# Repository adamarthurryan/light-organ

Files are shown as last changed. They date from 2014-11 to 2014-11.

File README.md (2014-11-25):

light-organ
===========

The light organ is an audio visualizer or special effects controller. The device is an electronic a 3-channel dimmer for incandescent lights. Each channel interprets the amplitude of one frequency band from the input audio.

This device was used in the interactive sound ard installation "infinite space kaleidoscope" by Adam Brown. See http://madanworb.com/blog/2011/02/01/infinite-space-kaleidoscope/

# Hardware

The dimmer is implemented with TRIAC switches, signaled through optoisolators. The dimmer controller and sound analyzer is implemented with an Atmel ATXMega128A1 8-bit microcontroller. 

The dimmer circuitry also provides a rectified AC-sync signal at 2.5V. The controller analyzes this signal to determine when the TRIAC should be switched on at each point in the AC waveform. (Recall that TRIACs can only be switched off at zero-crossing, so dimmer PWM has to be syncronized to the AC carrier wave.)

Circuits were designed in the free edition of Eagle. Schematics and burnable board layouts are included in the "circuits/light organ base" and "circuits/light organ controller" folders.

# Software

The controller software is implemented for the Atmel ATXMega128A1 - an 8-bit, 32MHz microcontroller. The responsibilities of the controller software are to:
- analyze an input waveform to find amplitudes in the three target frequency bands
- analyze the AC-sync signal to determine the mains frequency and phase
- signal the amplitude for each channel by switching the TRIACs

The software is developed and compiled with Atmel AVR Studio and depends on the XMega appnote library.

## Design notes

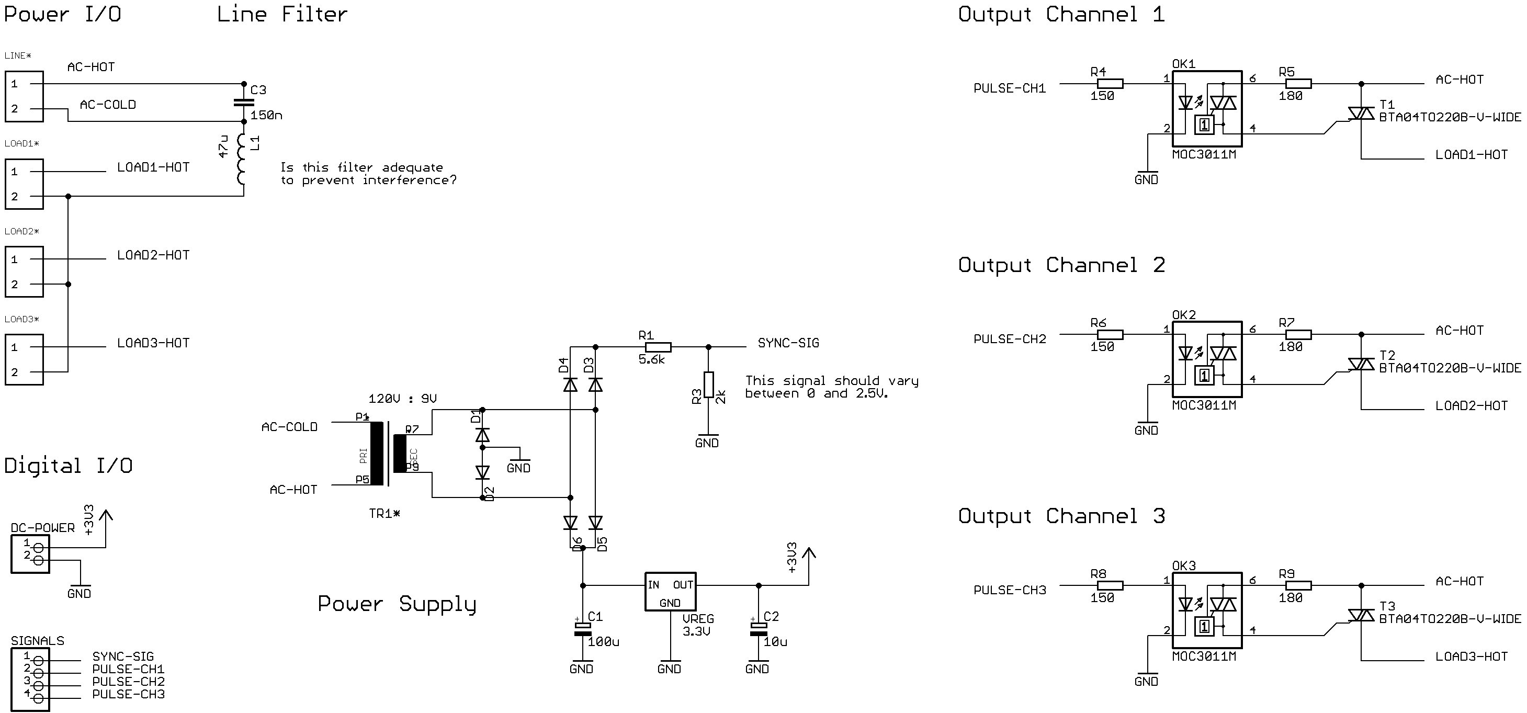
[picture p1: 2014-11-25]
circuits/light organ base/schematic.png

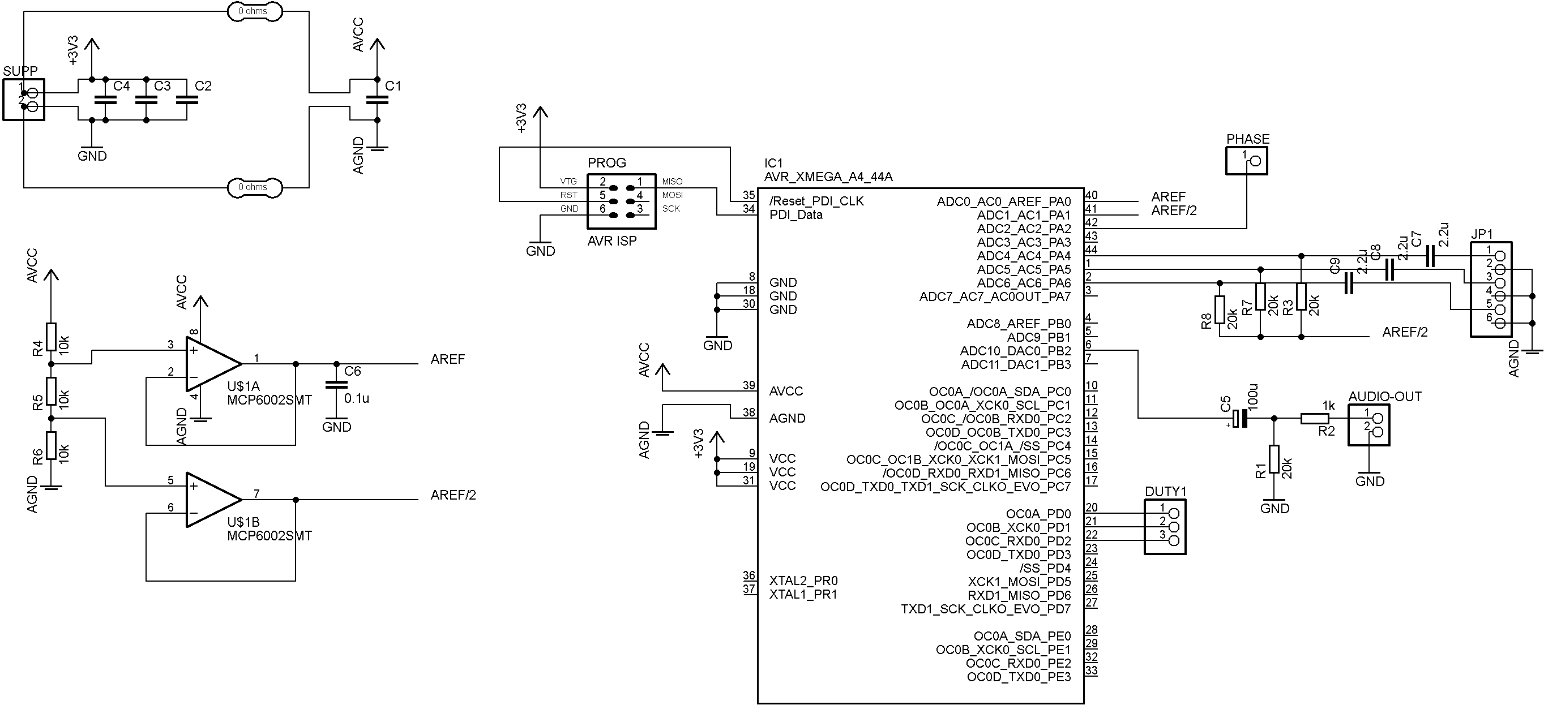
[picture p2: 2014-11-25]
circuits/light organ controller XMEGA A4/schematic.png

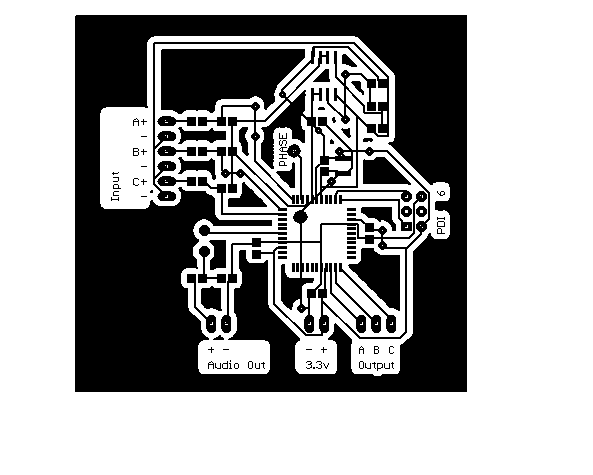
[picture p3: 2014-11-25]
circuits/light organ controller XMEGA A4/board.png

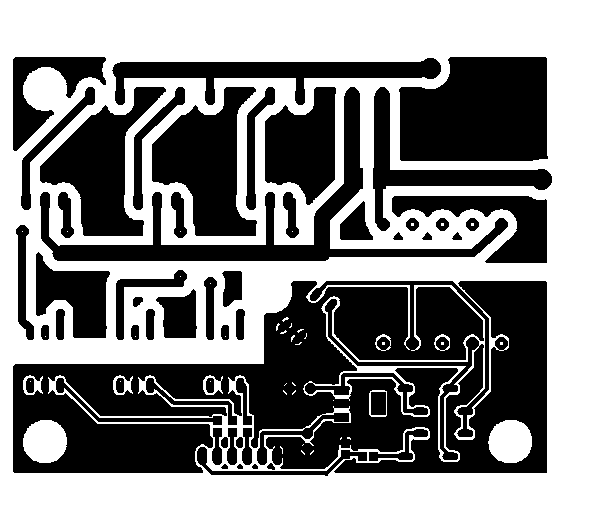
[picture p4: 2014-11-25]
circuits/light organ base/board.png

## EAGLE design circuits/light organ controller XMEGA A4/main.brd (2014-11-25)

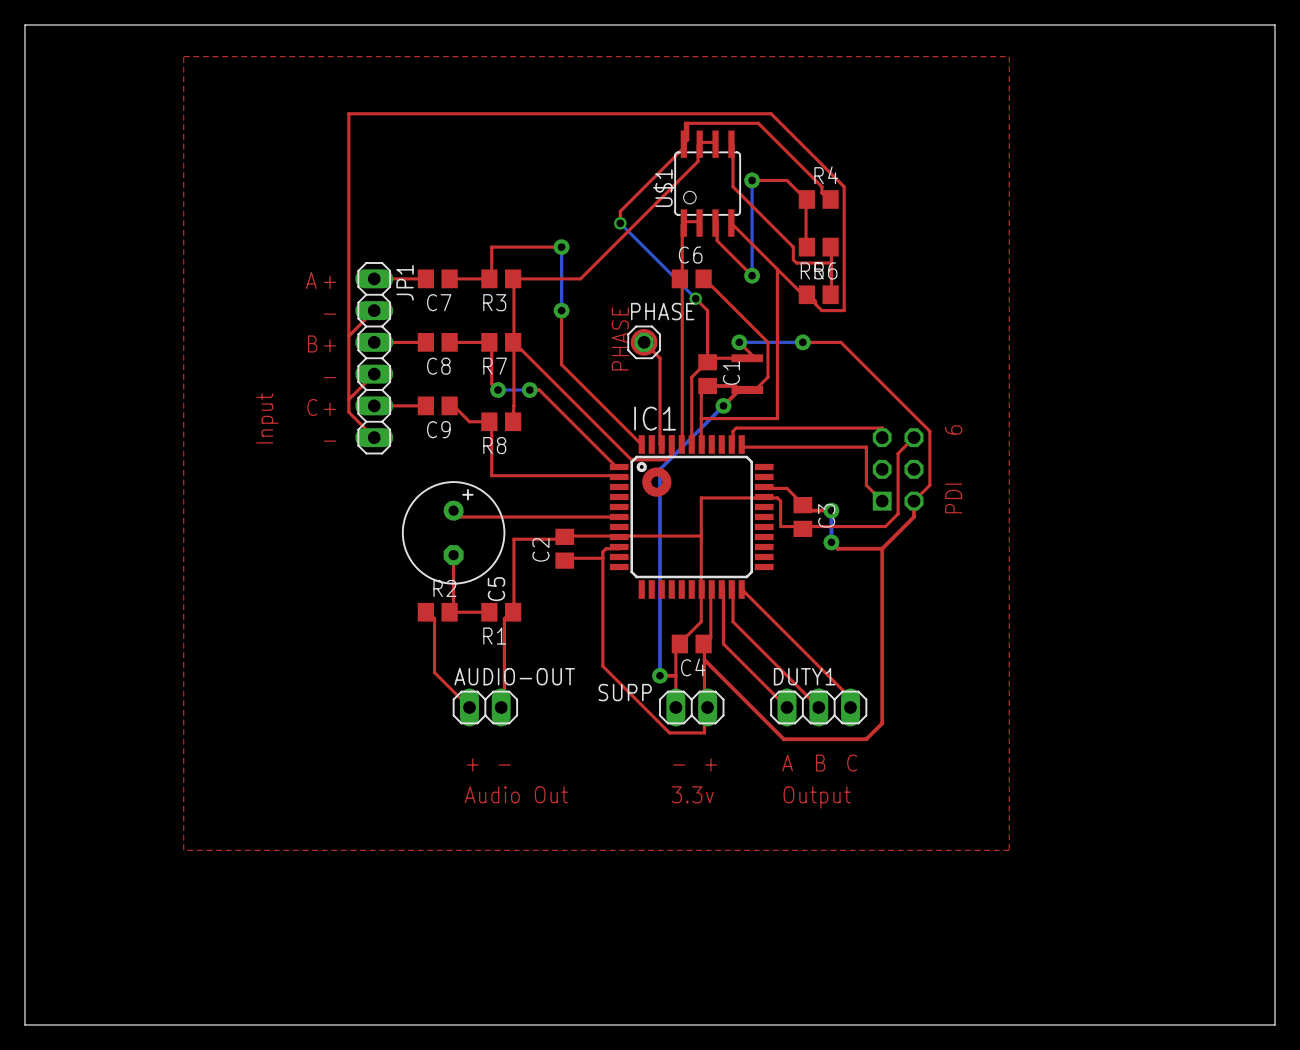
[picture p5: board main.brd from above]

Board: 2 copper layers, 100.0 x 80.0 mm, 27 parts (1 on the bottom side), 23 nets.

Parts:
AUDIO-OUT: 1X02
C1, C2, C3, C4: C0805
C5: 100u; E3,5-8
C6: 0.1u; C0805
C7, C8, C9: 2.2u; C0805
DUTY1: 1X03
IC1: AVR_XMEGA_A4_44A; TQFP44
JP1: 1X06
PHASE: 1X01
PROG: AVR-ISP-6
R1, R3, R7, R8: 20k; R0805
R2: 1k; R0805
R4, R5, R6: 10k; R0805
SUPP: 1X02
U$1: MCP6002SMT; SOIC8
U$2, U$4: RESISTOR-0; JOINED-PADS

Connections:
+3V3: C2.1, C3.1, C4.1, IC1.9, IC1.19, IC1.31, PROG.2, SUPP.1, U$2.P$1
AGND: C1.2, IC1.38, JP1.2, JP1.4, JP1.6, R6.1, U$1.4, U$4.P$2
AREF: C6.1, IC1.40, U$1.1, U$1.2
AREF/2: IC1.41, R3.1, R7.1, R8.1, U$1.6, U$1.7
AVCC: C1.1, IC1.39, R4.2, U$1.8, U$2.P$2
GND: AUDIO-OUT.2, C2.2, C3.2, C4.2, C6.2, IC1.8, IC1.18, IC1.30, PROG.6, R1.1, SUPP.2, U$4.P$1
IN1: C7.2, JP1.1
unnamed: IC1.35, PROG.5
unnamed: C5.+, IC1.6
unnamed: IC1.34, PROG.1
unnamed: C5.-, R1.2, R2.2
unnamed: AUDIO-OUT.1, R2.1
unnamed: C7.1, IC1.44, R3.2
unnamed: IC1.42, PHASE.1
unnamed: C8.2, JP1.3
unnamed: R4.1, R5.2, U$1.3
unnamed: R5.1, R6.2, U$1.5
unnamed: C9.2, JP1.5
unnamed: C8.1, IC1.1, R7.2
unnamed: C9.1, IC1.2, R8.2
unnamed: DUTY1.1, IC1.20
unnamed: DUTY1.2, IC1.21
unnamed: DUTY1.3, IC1.22

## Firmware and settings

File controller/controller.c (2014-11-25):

/*
	Light Organ

	Improvements to be made:
		allow multiple input sources (multiple ADC channels)
		allow switches to configure input source, or filter bands
		incorporate beat detection
		increase the duty cycle setting resolution (to 11 bits, say)

	Problems:
		the low pass filter always seems to register a signal
		maybe this is 60 Hz hum?
*/

/* !!! try flattening dynamics of output:
	- clip output to 0 / 1 
 try other frequency bands*/

#include <avr/io.h>

//standard library
#include <stdbool.h>
#include <stdint.h>
#include <stdlib.h>
#include <stdio.h>
#include <math.h>
#include <util/delay.h>


//peripheral drivers
#include "clksys_driver.h"
#include "event_system_driver.h"
#include "tc_driver.h"
#include "pmic_driver.h"
#include "ac_driver.h"
#include "adc_driver.h"
#include "dac_driver.h"

//device drivers
#include "display.h"


//helper
	#define max(a,b) ((a>b)?a:b)
	#define min(a,b) ((a<b)?a:b)

//filter options
	#define FILTERS_ENABLE
//	#define ANTIALIAS_ENABLE
	#define ANTIALIAS_RATE 2
	//the following is log(ANTIALIAS_RATE)
	#define ANTIALIAS_SHIFT 1

//input options
	#define INPUT_CLONE_SAMPLE0

//debug-mode options
//	#define DISPLAY_ENABLE
//	#define	FLASHER_ENABLE

//	#define PRINT_DEBUG
//	#define PRINT_DUTY_CYCLES

	#define DEBUG_FILTER_TEST
//	#define DEBUG_CLONE_DUTY0

//peripheral configuration
	#define UI_timer TCD0
	#define UI_vect TCD0_OVF_vect

	#define ms_UI_interval 1

	#define PHASE_timer TCE0
	#define PHASE_port PORTD

	#define EFFECTIVE_rate 11000
	#ifdef ANTIALIAS_ENABLE
		#define SAMPLE_rate (EFFECTIVE_rate * ANTIALIAS_RATE)
	#endif
	#ifndef ANTIALIAS_ENABLE
		#define SAMPLE_rate EFFECTIVE_rate
	#endif

	#define SAMPLE_timer TCD1
	#define SAMPLE_evsrc EVSYS_CHMUX_TCD1_OVF_gc

	#define CAPTURE_timer TCC1
	#define CAPTURE_vect TCC1_OVF_vect
	
	//the number of samples to collect in a bin for the beat detection algorithm
	//binsize must equal 2^binbits
	//note that the sound intensity will be sampled at rate/binsize, choose a binsize to make this around 40 Hz
	#define CAPTURE_binsize 256 //### 1024 //### 32 //###256
	#define CAPTURE_binbits 8 //### 10 //### 5 //###8
	
	#define HISTORY_size 43 //### 43

	#define AC_pin AC_MUXPOS_PIN2_gc

	//the gain for the ADC
	//this is configured for use with line level audio
	#define ADC_gain ADC_CH_GAIN_2X_gc

	//the pin for the AREF / 2 mid level reference voltage (for positive and negative ADC MUX)
	#define ADC_AREF_DIV_2_MUXPOS_pin ADC_CH_MUXPOS_PIN1_gc
	#define ADC_AREF_DIV_2_MUXNEG_pin ADC_CH_MUXNEG_PIN1_gc

//event related variables
	volatile uint32_t msClock=0;

	//these phase variables are expressed in terms of ticks of the phase clock
	uint16_t phasePeriod=0;
	volatile uint16_t phasePeriodLast=0;
	uint16_t phasePeriodMin=3200;

	volatile bool fPhaseBegin=false;
	volatile bool fPhaseEnd=false;
	volatile bool fSampleCaptured=false;
	volatile bool fCaptureBinFilled=false;

//	volatile uint16_t sampleLast=0;
//	volatile uint16_t sampleMax=0;
//	volatile uint16_t sampleMin=4096;

//	volatile uint32_t sampleSum=0;
//	volatile uint16_t sampleSumCount=0;

	volatile uint8_t dutyA, dutyB, dutyC;

//debugging variables
	volatile uint16_t debug1, debug2, debug3, debug4;

//a string for building output
	char string [17];

//the error offset of the adc
	int16_t ADC_offset=0;




//function prototypes
	void initializeMCU();
	void initializeUITimer();
	void initializePhaseTimer();
	void initializePhaseComparator();
	void initializeSampleTimer();
	void initializeCaptureTimer();
	void initializeADC();

	void initializeDAC();

	void enableInterrupts();

	void setDutyCycles(uint8_t, uint8_t, uint8_t);
	void findPhasePeriod();

	void error(char *);

	void printDutyCycles();
	void debugFilterTest();

int main(void) {

	//initialize the MCU clock
	initializeMCU();

	#ifdef DEBUG_FILTER_TEST
		debugFilterTest();
	#endif

	//initialize the display and display the title if the display is enabled
	#ifdef DISPLAY_ENABLE
		//initialize the display (the SPI port)
		display_init(16,2);	

		//display the boot screen
		display_returnHome();
		display_printString("Light Organ");
		
	#endif
	
	//initialize peripherals
	initializeUITimer();
	initializePhaseTimer();
	initializePhaseComparator();

	#ifndef FLASHER_ENABLE
		initializeSampleTimer();
		initializeCaptureTimer();
		initializeADC();
		initializeDAC();
	#endif

	enableInterrupts();
	
//	while (true) {
		//find the nominal phase period
		findPhasePeriod();	

		//### hack - because the phase period detection is not working
		//phasePeriod=1800;


		//display the period if the display is enabled
		#ifdef DISPLAY_ENABLE
			display_moveCursor(0x40);
			sprintf(string, "period: %i", phasePeriod);
			display_printString(string);
//			_delay_ms(1000);
			_delay_ms(300);
		#endif
//	}

	#ifdef DISPLAY_ENABLE
		volatile uint32_t msDisplayUpdate=0;
		#define DISPLAY_PERIOD 100
	#endif


	//some variables for generating fun duty cycle changes
	#ifdef FLASHER_ENABLE
		int value=1;
		int dir=1;
		int step=2;
		int stepdir=1;
		int stepstep=1;
	#endif

	volatile uint32_t msValueUpdate=0;
//	uint16_t energy=0;
	volatile uint32_t msStrobe=0;

	//enter the main event loop
	while (true) {
		//keep track of the minimum phase period
		if (fPhaseEnd) {

			//PHASE_port.OUTCLR = PIN0_bm;
			fPhaseEnd=false;
			phasePeriodMin=(phasePeriodLast<phasePeriodMin) ? phasePeriodLast : phasePeriodMin;
			//debug3=phasePeriodLast;
		}

//		if(msClock>=msStrobe) {
//			PHASE_port.OUTTGL=PIN1_bm;
//			msStrobe=msClock+2;
//		}


		#ifdef FLASHER_ENABLE
			//update the value to create a flashing light effect
			if (msClock>=msValueUpdate) {
				setDutyCycles(value, 255-value, 255-value);

				phasePeriodMin=30000;

				if (step<=1 || step>=128)
					stepdir=-stepdir;

				if (value<=0 || value>=255) {
					dir=-dir;
					step+=stepdir*stepstep;
				}
				value+=dir*step;

				if (value<0) value=0;
				if (value>255) value=255;
			
				msValueUpdate+=30;
			}
		#endif



		//update the display
		#ifdef DISPLAY_ENABLE
			if (msClock>=msDisplayUpdate) {
				display_moveCursor(0x0E);
				display_printString("  ");

				if (fSampleCaptured) {
					display_moveCursor(0x0E);
					display_printChar('S');
					fSampleCaptured=false;
				}

				if (fCaptureBinFilled) {
					display_moveCursor(0x0F);
					display_printChar('F');
					fCaptureBinFilled=false;
				}

				#ifdef PRINT_DEBUG
					sprintf(string, "%5i ", debug1);
					display_moveCursor(0x00);
					display_printString(string);

					sprintf(string, " %5i", debug2);
					display_moveCursor(0x06);
					display_printString(string);

					sprintf(string, "%5i ", debug3);
					display_moveCursor(0x40);
					display_printString(string);

					sprintf(string, " %5i", debug4);
					display_moveCursor(0x46);
					display_printString(string);
				#endif

				#ifdef PRINT_DUTY_CYCLES
					printDutyCycles();
				#endif

				msDisplayUpdate+=DISPLAY_PERIOD;
			}
		#endif

	}
}


//print the duty cycle to the display
void printDutyCycles() {
	sprintf(string, "a:%2X, b:%2X, c:%2X", dutyA, dutyB, dutyC);
	display_moveCursor(0x40);
	display_printString(string);
}

//set the duty cycle for each output channel
//duty cycle is expressed as a byte value
//0 is fully off, 255 is fully on
void setDutyCycles(uint8_t _dutyA, uint8_t _dutyB, uint8_t _dutyC) {
	//save the duty settings as global variables (for debugging)
	dutyA=_dutyA; dutyB=_dutyB; dutyC=_dutyC;

	//calculate the number of ticks given the duty cycle
	uint32_t prodA = (uint32_t) _dutyA * phasePeriod;
	uint16_t ticksA= phasePeriod - (prodA/255);

	//set the timer comparator value
	//the comparator output pins for the phase timer will be the duty cycle output
	TC_SetCompareA(&PHASE_timer, ticksA);

	uint32_t prodB = (uint32_t)_dutyB * phasePeriod;
	uint16_t ticksB=phasePeriod - (prodB/255);
	//note: comparator B didn't work, for some reason, so we use comparator D for output channel B instead
	TC_SetCompareD(&PHASE_timer, ticksB);

	uint32_t prodC = (uint32_t)_dutyC * phasePeriod;
	uint16_t ticksC=phasePeriod - (prodC/255);
	TC_SetCompareC(&PHASE_timer, ticksC);
	
//	debug1=(uint16_t) (prodA/255);
//	debug2=ticksA;
}

//find the noninal AC phase
void findPhasePeriod() {
	uint32_t sum=0;

	uint32_t msTimeout=msClock+10000;

	//average the phase period over one second
	for (int i=0;i<60;i++) {
		while (!fPhaseEnd) {
			if (msClock>=msTimeout)
				error("finding period");
		}
		fPhaseEnd=false;

		sum+=phasePeriodLast;
	}

	phasePeriod=sum/60;
}




//show an error and hang
void error(char * msg) {
	display_clear();
	_delay_ms(3);

	display_moveCursor(0x00);
	display_printString("ERROR");
	display_moveCursor(0x40);
	display_printString(msg);

	while (true) 
		nop();
}

//the UI timer interrupt
ISR(UI_vect)
{
	msClock+=ms_UI_interval;
}




//the analog comparator rising edge interrupt
//note this is mislabeled as "COMP0_vect" in the ATXMEGA datasheet!
ISR(ACA_AC0_vect)
{
	//turn on the counter
	TC0_ConfigClockSource(&PHASE_timer, TC_CLKSEL_DIV64_gc);   

	//flag that a zero-cross rising edge event has occured
	fPhaseBegin=true;

}

//the analog comparator falling edge interrupt
//note this is mislabeled as "COMP1_vect" in the ATXMEGA datasheet!
ISR(ACA_AC1_vect)
{
	//turn off phase timer
	TC0_ConfigClockSource(&PHASE_timer, TC_CLKSEL_OFF_gc);   

	//reset the output pins
	PHASE_port.OUTCLR = PIN0_bm | PIN1_bm | PIN2_bm;

	//force update of compare values
	//this would normally happen when the counter overflows
	TC_ForceUpdate(&PHASE_timer);

	//read the counter
	phasePeriodLast=PHASE_timer.CNT;

	//set the counter to 0 and clear the comparators
	TC_Restart(&PHASE_timer);

	//flag that a zero-cross falling edge event has occured
	fPhaseEnd=true;

}

//the interrupts for the comparators - when a comparator is triggered, turn on the cooresponding pin
//these could possibly be optimized by making them ISR_NAKED and doing the setup by hand
ISR(TCE0_CCA_vect) {
	PHASE_port.OUTSET = PIN0_bm;
}
ISR(TCE0_CCD_vect) {
	PHASE_port.OUTSET = PIN1_bm;
}
ISR(TCE0_CCC_vect) {
	PHASE_port.OUTSET = PIN2_bm;
}


//record the maximum sample level for debugging
uint16_t maxLevel=0;

//the number of input channels
#define INPUT_CHANNELS 3

//!!! These should be initialized to 0
//keeps a running tally of the energy for each sample
uint32_t energy_sum[INPUT_CHANNELS];


#ifdef FILTERS_ENABLE
	//the following variables are used for the three bandpass filters
	int32_t lowband_x0=0, lowband_x1=0, lowband_x2=0;
	int32_t lowband_y0=0, lowband_y1=0, lowband_y2=0;

	int32_t midband_x0=0, midband_x1=0, midband_x2=0;
	int32_t midband_y0=0, midband_y1=0, midband_y2=0;

	int32_t highband_x0=0, highband_x1=0, highband_x2=0;
	int32_t highband_y0=0, highband_y1=0, highband_y2=0;
 
 	#define FILTER_CONSTANT_SHIFT 12

//These were created using Interactive Digital Filter Design, http://www-users.cs.york.ac.uk/~fisher/mkfilter
// (and made fixed point with filters.php)
// they are shifted to have 12 fractional bits (ie. Q20.12 format)

// lowband_: 160-320 HZ
#define lowband_INVGAIN 386
#define lowband_B0 3549
// midband_: 2500-4000 HZ
#define midband_INVGAIN 1603
#define midband_B0 -891
#define midband_B1 -843
// highband_: 4000-5500 HZ
#define highband_INVGAIN 1572
#define highband_B0 -1139
#define highband_B1 -4864

	//compute a fast lowpass filter using the given parameters and sample history
	//the filter constants are assumed to have FILTER_CONSTANT_SHIFT fractional bits
	#define fastlowpass(sample, x0, x1, y0, y1, invgain, b0) \
		x0=x1; y0=y1;\
		x1=(sample*invgain);\
		y1=((x0+x1) + (b0 *y0)) >> FILTER_CONSTANT_SHIFT;\
		sample=y1;

	//compute a fast bandpass filter using the given parameters and sample history
	//the filter constants are assumed to have FILTER_CONSTANT_SHIFT fractional bits
	#define fastbandpass(sample, x0, x1, x2, y0, y1, y2, invgain, b0, b1) \
		x0=x1; x1=x2; y0=y1; y1=y2;\
		x2=(sample*invgain) ;\
		y2=((x2-x0) + (b0*y0) + (b1*y1)) >> FILTER_CONSTANT_SHIFT;\
		sample=y2;


	#ifdef DEBUG_FILTER_TEST
		#define TEST_SAMPLES 16
		#define TO_FIXED(x) ((int32_t)(x*(1<<12)))
		#define TO_FIXED_SMP(x) ((int32_t)(x*2048))
		void debugFilterTest() {
			int16_t results[TEST_SAMPLES];
		
			int32_t x0=0, x1=0, x2=0, y0=0, y1=0, y2=0;
			int32_t b0 = lowband_B0;
			int32_t b1 = 0;
			int32_t invgain = lowband_INVGAIN;
		

			int32_t x0_hist [TEST_SAMPLES];			
			int32_t x1_hist [TEST_SAMPLES];			
			int32_t x2_hist [TEST_SAMPLES];			
			int32_t y0_hist [TEST_SAMPLES];			
			int32_t y1_hist [TEST_SAMPLES];			
			int32_t y2_hist [TEST_SAMPLES];			

			int32_t sample=2048;
			fastlowpass(sample, x0, x1, y0, y1, invgain, b0);
			//for (int i=0; i<1000; i++) {
			//	sample=0;
			//	fastlowpass(sample, x0, x1, y0, y1, invgain, b0);
			//}
			

			for (int i=0; i<TEST_SAMPLES; i++) {
				sample=0;
				fastlowpass(sample, x0, x1, y0, y1, invgain, b0);

				x0_hist[i]=x0;
				x1_hist[i]=x1;
				x2_hist[i]=x2;
				y0_hist[i]=y0;
				y1_hist[i]=y1;
				y2_hist[i]=y2;
				results[i]=y2;
			}

			__builtin_avr_delay_cycles(4);
		}
	#endif


#endif

#ifdef ANTIALIAS_ENABLE
	int32_t antialias_sample[INPUT_CHANNELS];
	int8_t antialias_count=0;
#endif

//the sample capture interrupt from the ADC
//the ADC conversion is triggered by the sample timer and this ISR is called when the conversion is complete
ISR(ADCA_CH0_vect) {
	

	//int16_t sample[INPUT_CHANNELS];
	int32_t sample[INPUT_CHANNELS];

	//read the samples (signed)
	sample[0]=ADC_ResultCh_GetWord_Signed(&ADCA.CH0, ADC_offset);

	#ifndef INPUT_CLONE_SAMPLE0
		sample[1]=ADC_ResultCh_GetWord_Signed(&ADCA.CH1, ADC_offset);
		sample[2]=ADC_ResultCh_GetWord_Signed(&ADCA.CH2, ADC_offset);
	#endif




//FUDGE FACTOR!!!
	sample[0]-=84;


#ifdef ANTIALIAS_ENABLE
	//sample into the antialiasing filter
	antialias_sample[0]+=sample[0];

	//only process channels 1 and 2 if necessary
	#ifndef INPUT_CLONE_SAMPLE0
		antialias_sample[1]+=sample[1];
		antialias_sample[2]+=sample[2];
	#endif

	antialias_count++;

	//if the antialiasing filter is "full" output the signal
	if (antialias_count>=ANTIALIAS_RATE) {
		sample[0] = antialias_sample[0] >> ANTIALIAS_SHIFT;
		antialias_sample[0]=0;
		//only process channels 1 and 2 if necessary
		#ifndef INPUT_CLONE_SAMPLE0
			sample[1] = antialias_sample[1] >> ANTIALIAS_SHIFT;
			sample[2] = antialias_sample[2] >> ANTIALIAS_SHIFT;
			antialias_sample[1]=0;
			antialias_sample[2]=0;
		#endif
				
		
#endif

#ifndef ANTIALIAS_ENABLE
	if (true) {
#endif

		#ifdef INPUT_CLONE_SAMPLE0
			sample[1]=sample[0];
			sample[2]=sample[0];
		#endif

		#ifdef FILTERS_ENABLE
			debug1=sample[0];
			fastlowpass(sample[0], lowband_x0, lowband_x1, lowband_y0, lowband_y1, lowband_INVGAIN, lowband_B0);
		//	sample[0]=0;

		//more FUDGE!!!
			sample[0]-=35;

			debug2=sample[1];
			fastbandpass(sample[1], midband_x0, midband_x1, midband_x2, midband_y0, midband_y1, midband_y2, midband_INVGAIN, midband_B0, midband_B1);

			debug3=sample[2];
			fastbandpass(sample[2], highband_x0, highband_x1, highband_x2, highband_y0, highband_y1, highband_y2, highband_INVGAIN, highband_B0, highband_B1);

		#endif

		//###
		//	sample[0]=sample[0]>>6;
		//	sample[0]=sample[0]<<6;

		//this is only for sample 0?
	//	if (sample[0]>=0) 
	//		maxLevel=max(sample[0],maxLevel);
	//	else
	//		maxLevel=max(-sample[0], maxLevel);


		//take the energy of the samples and add them to the running total
		//we don't shift down by the full 16 (11?) bits, just to leave a little numerical resolution
		for (int i=0;i<INPUT_CHANNELS;i++)
			energy_sum[i]+=((int32_t)sample[i]*sample[i])>>2;

	
				// what about this instead of the square?
				//energy_sum_0+=(sample_0>=0)?sample_0:-sample_0;

		//put a sample to the DAC for debugging
		int16_t sampleOut=sample[0];
		DAC_Channel_Write(&DACB, (uint16_t) (sampleOut + 2048), CH0);//+ADC_offset/2, CH0);


		//increase the sample capture counter by sending event 4
		EVSYS_ManualTrigger(0, 0x10);


		//flag that the sample event occured
		fSampleCaptured=true;
	}
}



uint8_t historyIndex=0;
//should these arrays be initialized to 0?
uint16_t energy_history[INPUT_CHANNELS][HISTORY_size];

//uint32_t lowband_energy_historySum=0;
//uint32_t midband_energy_historySum=0;
//uint32_t highband_energy_historySum=0;

//this interrupt is called after every BINSIZE samples are filtered and summed into their three channels
//here we decide how to respond to the audio signal
ISR(CAPTURE_vect) {

	//###
	debug1=maxLevel;
	maxLevel=0;

	///
	// ** This algorithm is taken from http://www.gamedev.net/reference/articles/article1952.asp **
	///

	// * 1. Take the average input energy from the last bin of samples *
	uint16_t energy_inst[INPUT_CHANNELS];
	
	for (int i=0;i<INPUT_CHANNELS;i++) {
		//grab the sums lickety-quick so they don't change while we are processing
		//and divide them by BINSIZE to find their average
		energy_inst[i]=energy_sum[i] >> CAPTURE_binbits;

		//reset the sums
		energy_sum[i]=0;
	}

	
	// * 2.  Calculate the max and min history values for each input channel *

	uint16_t energy_max[INPUT_CHANNELS];
	uint16_t energy_min[INPUT_CHANNELS];
	
	uint16_t energy_all_max=0;
	uint16_t energy_all_min=65535;

	for (int i=0;i<INPUT_CHANNELS;i++) {
		//update the history array with the new values
		energy_history[i][historyIndex]=energy_inst[i];
		
		//now find maximum energy from the last HISTORY_size bin captures 
		//(this should be about a 1 second history)
		// the strength of the output channel will scale to this maximum

		energy_max[i]=0;
		energy_min[i]=65535;
		for (uint8_t j=0;j<HISTORY_size;j++) {
			energy_max[i]=max(energy_history[i][j],energy_max[i]);
			energy_min[i]=min(energy_history[i][j],energy_min[i]);
		}

		//find the max and min for all channels
		energy_all_max=max(energy_all_max,energy_max[i]);
		energy_all_min=min(energy_all_min,energy_min[i]);
	
	}

	// * 3. Fudge the max energy
		//this value is basically voodoo
		//it serves to ignore small variations in the energy though, basically requires a certain minimum intensity of sound to register a response
	for (int i=0;i<INPUT_CHANNELS;i++) {
		energy_max[i]=max(energy_max[i], 64);
	}
	energy_all_max=max(energy_all_max, 64); //was 16
	
	// * 3. Calculate the outputs *
		//for the time being, use the instantaneous energy, scaled to the maximum energy in the history
		// compare this to the instantaneous energy

		//other options are to use: 
		//	1) the rate of change of energy
		//	2) the difference of the energy from the 1 second background
		//	3) the simple instantaneous energy
		//  ...?

	uint8_t duty[INPUT_CHANNELS];
	for (int i=0;i<INPUT_CHANNELS;i++) {

/* this version uses just the max energy on the channel in question */
		if (energy_max[i]-energy_min[i]>1) {
			//scale the output to the maximum recent energy accross all channels 
				// (this removes all long-term dynamics)
			uint32_t scale = (((uint32_t)energy_inst[i] - energy_min[i]) *256) / (energy_max[i] - energy_min[i]);

			if (i==0) debug1=scale;

			duty[i] = min(scale,255);
		}

/* this version uses the max energy accross all channels
		if (energy_all_max-energy_all_min>1) {
			//scale the output to the maximum recent energy accross all channels 
				// (this removes all long-term dynamics)
			uint32_t scale = (((uint32_t)energy_inst[i] - energy_all_min) *256) / (energy_all_max - energy_all_min);

			if (i==0) debug1=scale;

			duty[i] = min(scale,255);
		}
*/

		//should we have a minimum duty value and scale relative to that?
	}	
	
	// * 4. Increment the history index *
	historyIndex++;
	if (historyIndex >= HISTORY_size)
		historyIndex = 0;

	
	debug2 = energy_inst[0];
	debug3 = energy_all_min;
	debug4 = energy_all_max;
	

	//copy the duty signal from channel 0 to the other channels for debugging
	#ifdef DEBUG_CLONE_DUTY0
		duty[1] = duty[0];
		duty[2] = duty[0];
	#endif


	#ifndef FLASHER_ENABLE
		//scale the duty cycle down to the range 0..255
		setDutyCycles(duty[0], duty[1], duty[2]);
	#endif


	fCaptureBinFilled=true;
}


//catch-all ISR - we shouldn't need this
//ISR(BADISR_vect)
//{
//    // user code here
//}

//set up the system clock
void initializeMCU() {
	//enable the 32MHz RC clock
	CLKSYS_Enable(OSC_RC32MEN_bm);
	//block till the clock is ready
	while (! CLKSYS_IsReady(OSC_RC32MRDY_bm)) {}
	//use the 32MHz RC clock as the main system clock
	CLKSYS_Main_ClockSource_Select(CLK_SCLKSEL_RC32M_gc);
}

//enable interrupts
void enableInterrupts() {
	PMIC_SetVectorLocationToApplication();
	PMIC_EnableLowLevel();
	PMIC_EnableMediumLevel();
	PMIC_EnableHighLevel();
	sei();
}

//set up a ui timer and enable its interrupt:
void initializeUITimer() {
	//set the mode
	TC0_ConfigWGM(&UI_timer, TC_WGMODE_NORMAL_gc);
	//set the clock source (prescale by 128)
	TC0_ConfigClockSource(&UI_timer, TC_CLKSEL_DIV256_gc);   
	//set the wave period (32 MHz / 256 = 125000 ticks / sec = 125 tics / ms)
	TC_SetPeriod( &UI_timer, 125*ms_UI_interval);
	//set the interupt
	TC0_SetOverflowIntLevel(&UI_timer, TC_OVFINTLVL_MED_gc);
}
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
